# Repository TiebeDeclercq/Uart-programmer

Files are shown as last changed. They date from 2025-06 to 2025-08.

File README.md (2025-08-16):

# Custom UART Programmer

A versatile UART programming board designed for microcontroller development with flexible voltage selection and multiple connection options. Features built-in status LEDs, CH340C USB-to-serial conversion, and support for external programming fixtures.

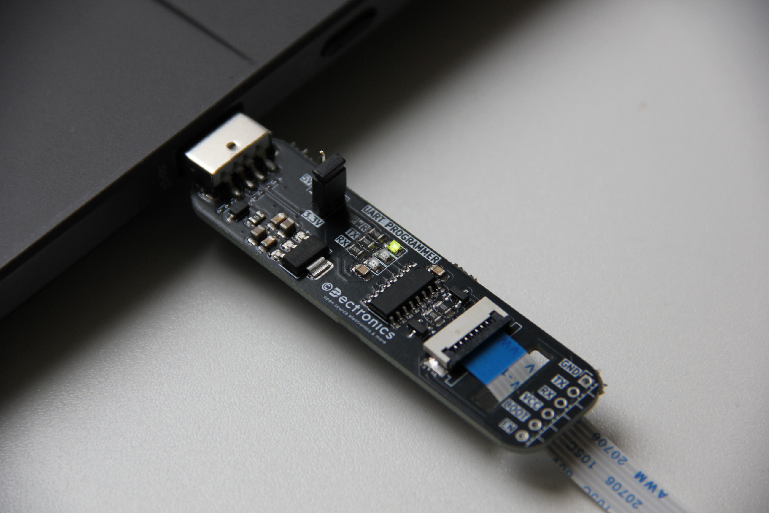
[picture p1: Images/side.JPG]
side

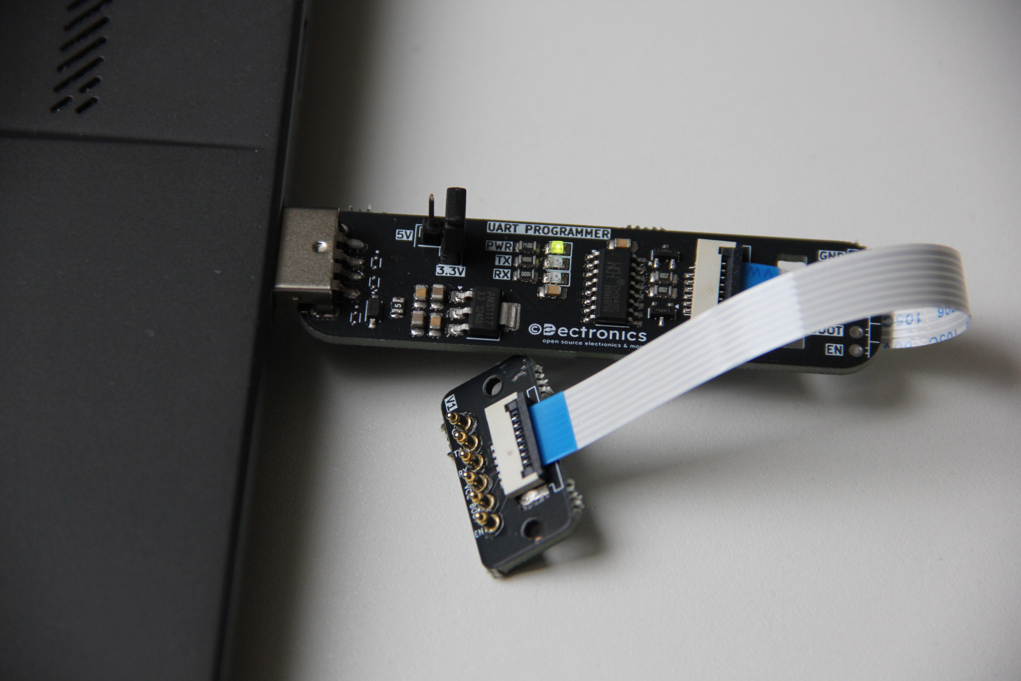
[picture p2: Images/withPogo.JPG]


## **Hardware Overview**

- **USB-to-Serial IC:** CH340C for reliable USB communication
- **Voltage Selection:** Jumper-selectable 3.3V or 5V operation
- **Status Indicators:**
    - Power LED (PWR)
    - TX/RX activity LEDs
- **Connection Options:**
    - Standard pin headers for jumper wire connections
    - FCP slot for external fixtures
- **Interface:** Standard UART (TX, RX, VCC, GND, BOOT, EN)
- **Power Supply:** USB-powered with onboard voltage regulation

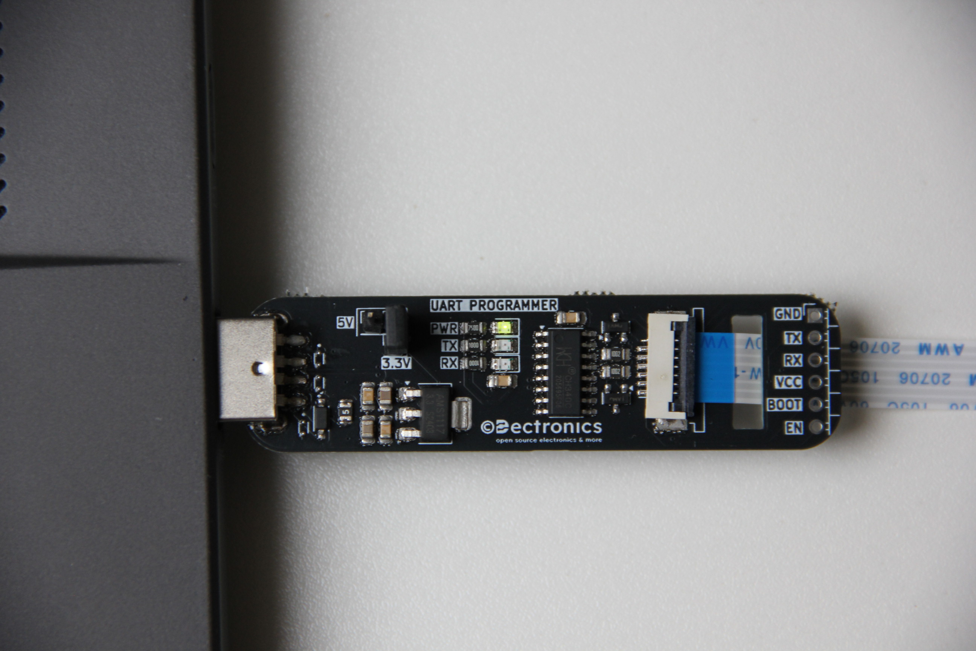
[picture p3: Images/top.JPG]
top

## **Schematic**


## **Getting Started**

1. **Driver Installation**
    
    - Install CH340 drivers for your operating system
    - Windows: Download from manufacturer or use Windows Update
    - macOS/Linux: Usually plug-and-play
2. **Voltage Selection**
    
    - Set jumper to 3.3V for ESP32, ESP8266, and other 3.3V microcontrollers
    - Set jumper to 5V for Arduino and 5V-compatible devices
3. **Connection Methods**
    
    **Method A: Direct Jumper Connections**
    
    - Connect VCC to target microcontroller's power pin
    - Connect GND to target ground
    - Connect TX to target RX pin
    - Connect RX to target TX pin
    - Use BOOT and EN pins for programming mode control (ESP32/ESP8266)
    
    **Method B: External Programming Fixture**
    
    - Insert compatible pogo pin module into FCP slot
    - Align fixture with target board
    - Programming connections are made automatically
4. **Programming**
    
    - Open your preferred serial terminal or IDE
    - Select the correct COM port
    - Set appropriate baud rate (typically 115200)
    - Put target microcontroller in programming mode
    - Upload firmware
5. **Status Monitoring**
    
    - PWR LED indicates power is applied
    - TX LED flashes during data transmission
    - RX LED flashes during data reception

**More Projects:** Visit [dectronics.cc](https://dectronics.cc/) for additional electronics projects

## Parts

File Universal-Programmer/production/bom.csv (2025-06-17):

Designator | Footprint | Quantity | Value | LCSC Part #
C1, C2 | 0805 | 2 | 100nF
C3, C5 | 0805 | 2 | 10uF
C4, C6 | 0805 | 2 | 0.1uF
D1, D2, D3 | 0805 | 3 | LED
D4 | SOD3715X145N | 1 | 1N5819HW-7-F
D5, D6, D7 | TVS_LESD5D5.0CT1G | 3 | LESD5D5.0CT1G
F1 | 0805 | 1 | Fuse_Small
J1 | USB_A_CNCTech_1001-011-01101_Horizontal | 1 | USB_A
J2 | PinHeader_1x06_P2.54mm_Horizontal | 1 | Conn_01x06_Pin
J4 | TE_84953-6_1x06-1MP_P1.0mm_Horizontal | 1 | Conn_01x06_MountingPin
Q1, Q2 | SOT-23 | 2 | MMBT3904
R1, R2 | 0805 | 2 | 10kΩ
R3 | 0805 | 1 | 750
R4, R5 | 0805 | 2 | 1k
U1 | SOIC-16_3.9x9.9mm_P1.27mm | 1 | CH340C
U2 | SOT-223-3_TabPin2 | 1 | AMS1117-3.3

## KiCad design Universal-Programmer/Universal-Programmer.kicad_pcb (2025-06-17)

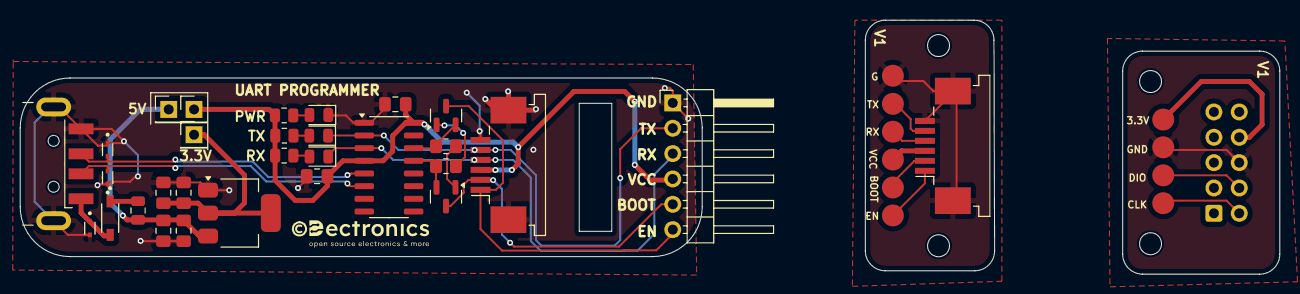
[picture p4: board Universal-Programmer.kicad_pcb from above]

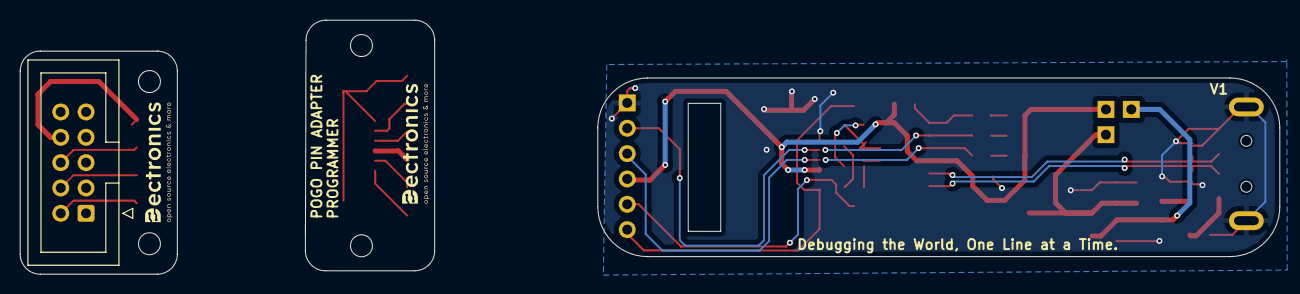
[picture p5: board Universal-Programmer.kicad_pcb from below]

Board: 2 copper layers, 126.2 x 25.5 mm, 43 parts (5 on the bottom side), 19 nets.

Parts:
C1, C2: 100nF; C_0805_2012Metric_Pad1.18x1.45mm_HandSolder
C3, C5: 10uF; C_0805_2012Metric_Pad1.18x1.45mm_HandSolder
C4, C6: 0.1uF; C_0805_2012Metric_Pad1.18x1.45mm_HandSolder
D1, D2, D3: LED; LED_0805_2012Metric
D4: 1N5819HW-7-F; SOD3715X145N
D5, D6, D7: LESD5D5.0CT1G; TVS_LESD5D5.0CT1G
F1: Fuse_Small; Fuse_0805_2012Metric
H1, H2, H3, H4: MountingHole; MountingHole_2.2mm_M2
J1: USB_A; USB_A_CNCTech_1001-011-01101_Horizontal
J2: Conn_01x06_Pin; PinHeader_1x06_P2.54mm_Horizontal
J3, J4: Conn_01x06_MountingPin; TE_84953-6_1x06-1MP_P1.0mm_Horizontal
J5, J6, J7, J8, J9, J10, J11, J12, J13, J14: Conn_01x01_Pin; HARWIN_P70-1000045R
J19: Conn_02x05_Odd_Even; IDC-Header_2x05_P2.54mm_Vertical
JP1: Jumper_3_Open; VoltageJumper
Q1, Q2: MMBT3904; SOT-23
R1, R2: 10kΩ; R_0805_2012Metric_Pad1.20x1.40mm_HandSolder
R3: 750; R_0805_2012Metric
R4, R5: 1k; R_0805_2012Metric
U1: CH340C; SOIC-16_3.9x9.9mm_P1.27mm
U2: AMS1117-3.3; SOT-223-3_TabPin2

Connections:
+3.3V: C3.1, C4.1, JP1.3 (B), U2.2 (VO)
+5V: C5.1, C6.1, F1.2, JP1.1 (A), U2.3 (VI)
/D_N: D6.2, J1.2 (D-), U1.6 (UD-)
/D_P: D5.2, J1.3 (D+), U1.5 (UD+)
BOOT: J2.5, J4.2, Q2.3 (C)
EN: J2.6, J4.1, Q1.3 (C)
GND: C1.1, C2.2, C3.2, C4.2, C5.2, C6.2, D1.1 (K), D5.1, D6.1, D7.2, J1.4 (GND), J1.5 (Shield), J2.1, J4.6, J4.MP (MountPin), U1.1 (GND), U2.1 (GND)
unnamed: D1.2 (A), R3.2
unnamed: D2.2 (A), R4.2
unnamed: D3.2 (A), R5.2
unnamed: D4.C, F1.1
unnamed: D4.A, D7.1, J1.1 (VBUS)
unnamed: Q1.1 (B), R1.2
unnamed: Q1.2 (E), R2.1, U1.14 (~RTS)
unnamed: Q2.1 (B), R2.2
unnamed: Q2.2 (E), R1.1, U1.13 (~DTR)
RX: D3.1 (K), J2.3, J4.4, U1.3 (RXD)
TX: D2.1 (K), J2.2, J4.5, U1.2 (TXD)
VCC: C1.2, C2.1, J2.4, J4.3, JP1.2 (C), R3.1, R4.1, R5.1, U1.4 (V3), U1.16 (VCC)
